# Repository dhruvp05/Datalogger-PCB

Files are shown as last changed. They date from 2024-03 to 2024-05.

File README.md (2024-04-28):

# Datalogger PCB

### Root

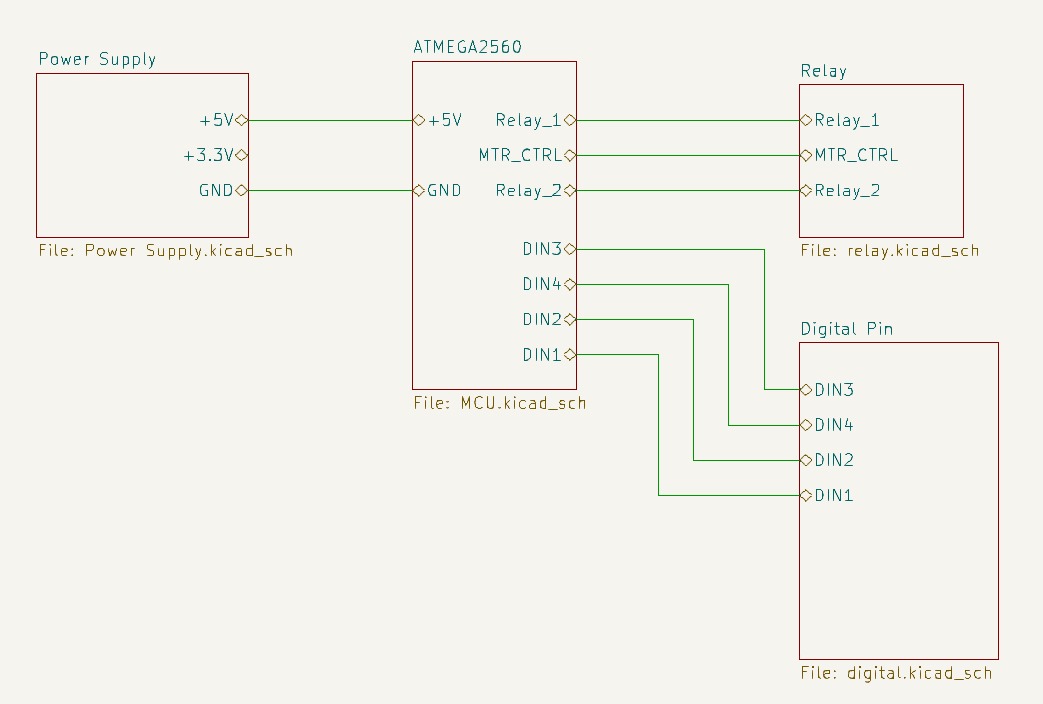
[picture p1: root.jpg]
Root


### Power Supply

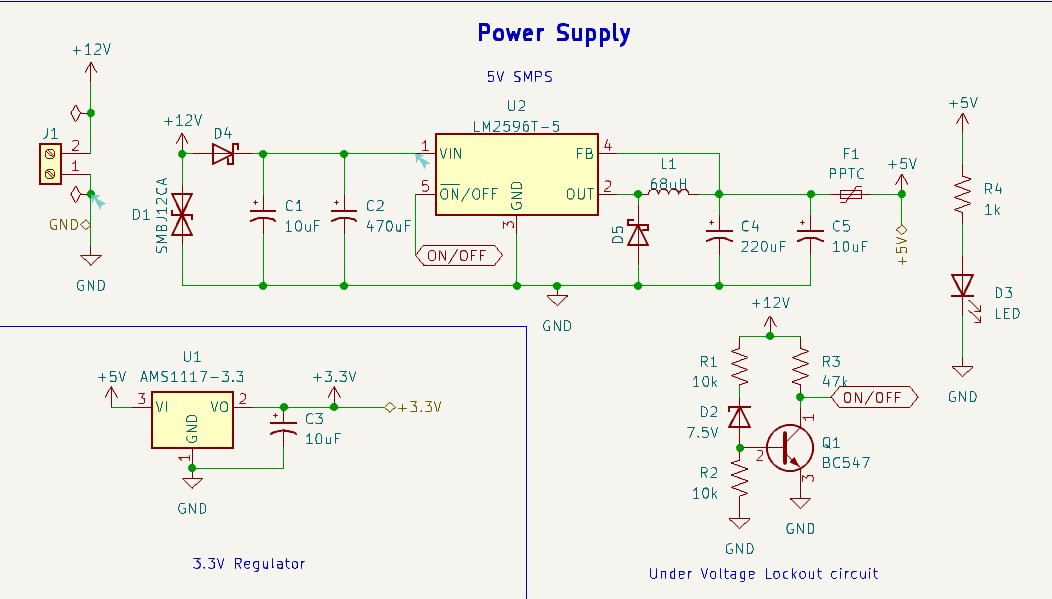
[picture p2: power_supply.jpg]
Power Supply


### Microcontroller

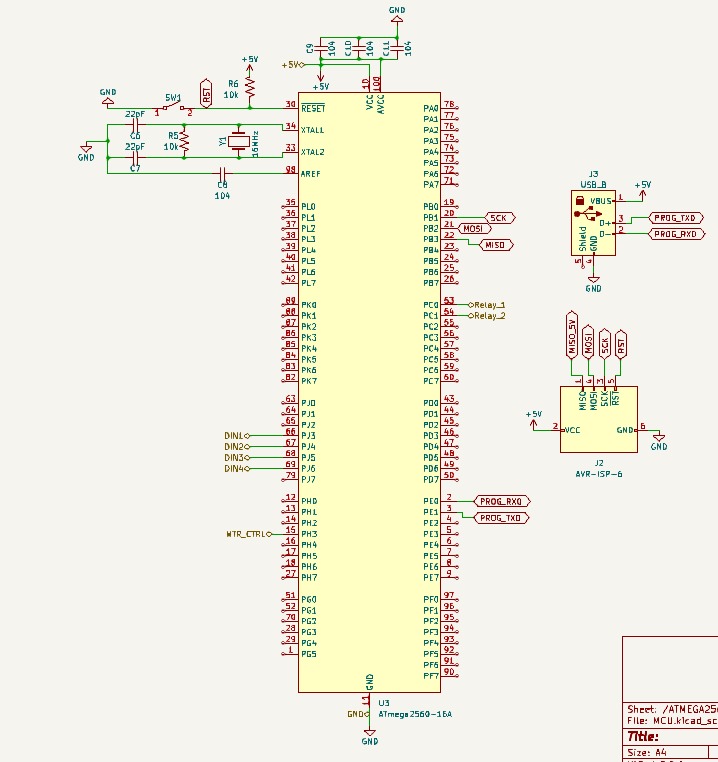
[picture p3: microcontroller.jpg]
Microcontroller


### Relay Motor

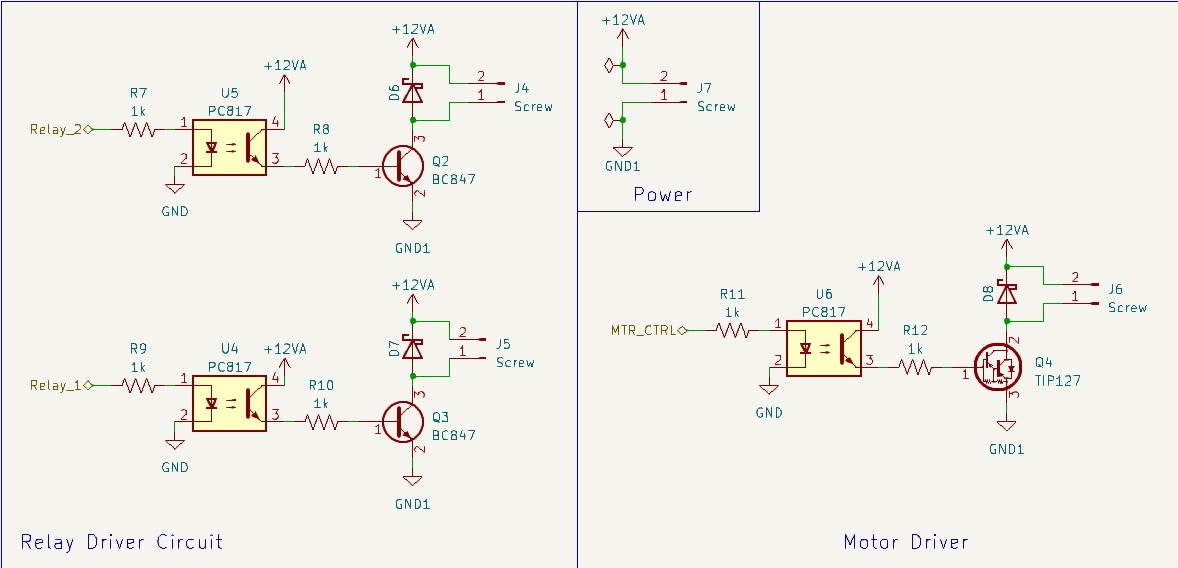
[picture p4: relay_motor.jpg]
Relay Motor


### Digital I/O

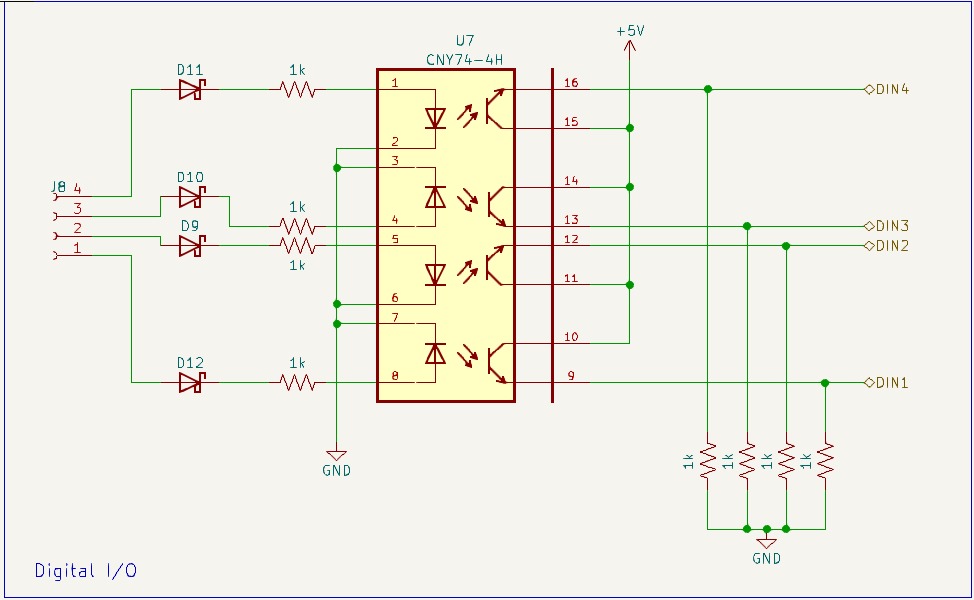
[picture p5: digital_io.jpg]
Digital I/O


### Layout

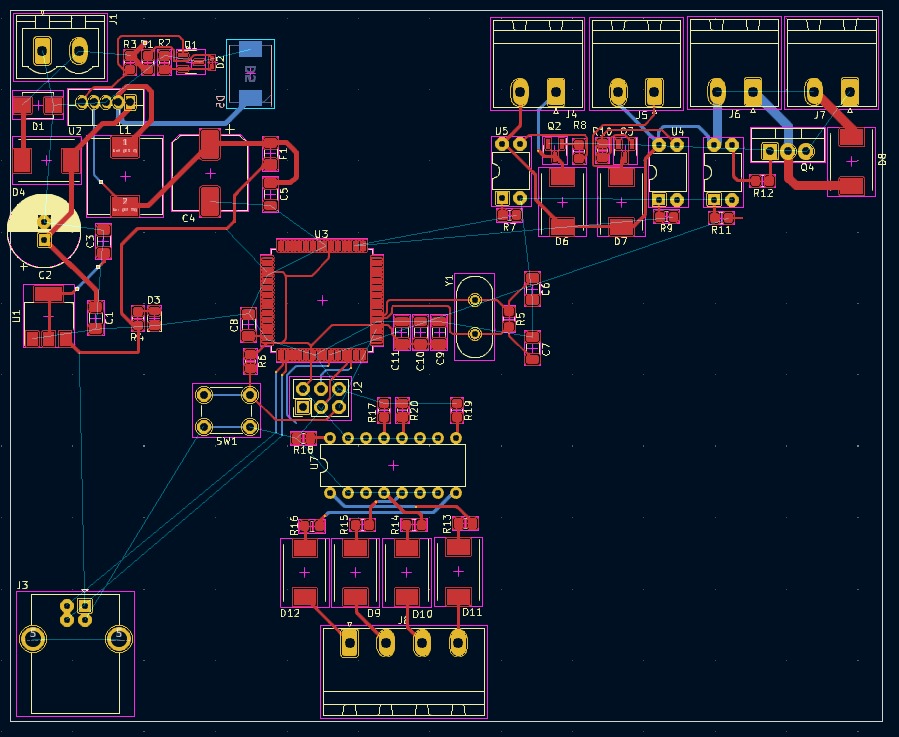
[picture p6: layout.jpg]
Layout


### 3D View

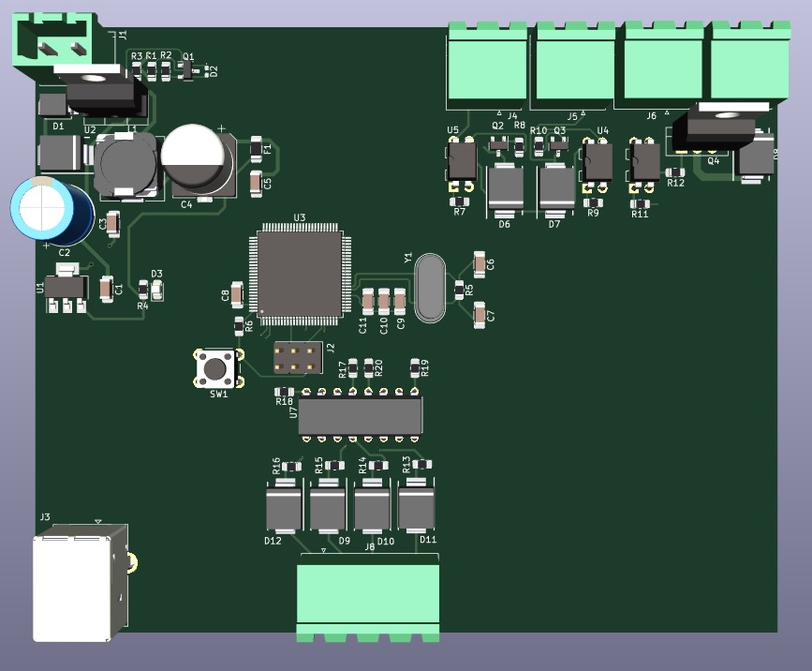
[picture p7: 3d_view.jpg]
3D View


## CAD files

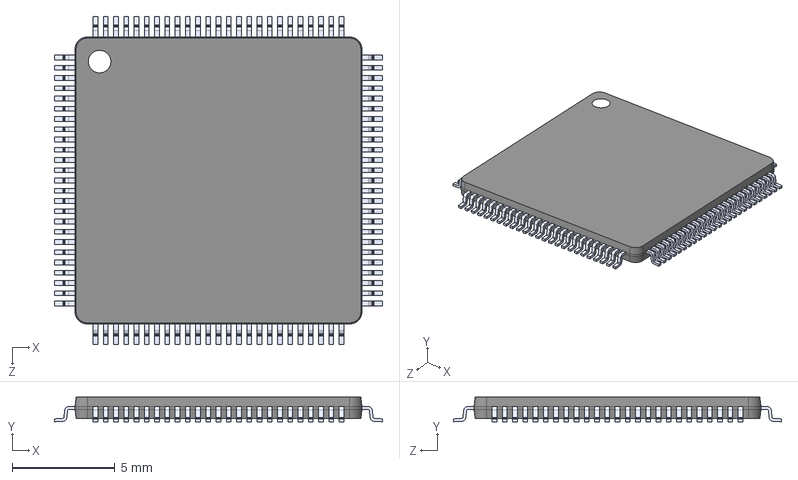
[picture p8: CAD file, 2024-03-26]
ATMEGA2560-16AU.step
16.0 x 1.20 x 16.0 mm

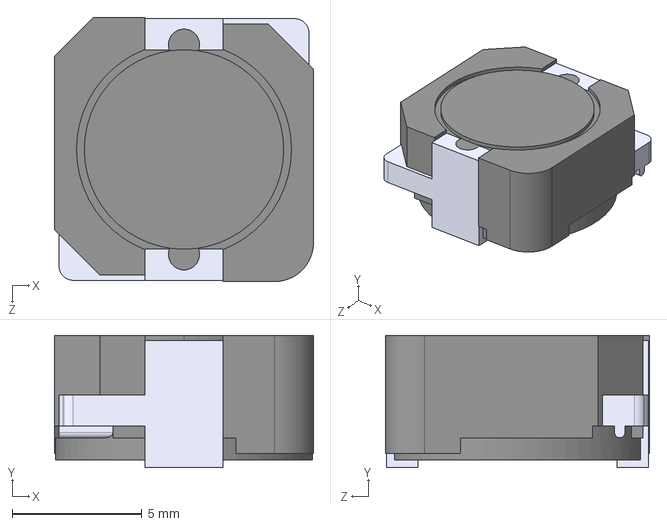
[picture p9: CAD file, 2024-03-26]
CDRH105RNP-151NC--3DModel-STEP-56544.STEP
10.0 x 5.10 x 10.2 mm

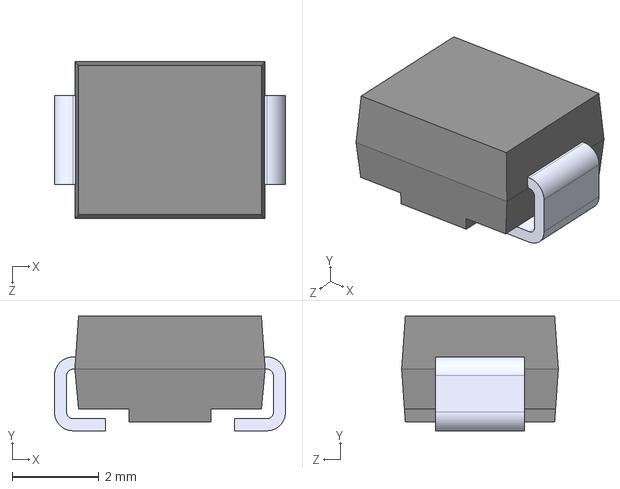
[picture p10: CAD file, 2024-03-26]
SMBJ12CA.STEP
5.34 x 2.65 x 3.62 mm

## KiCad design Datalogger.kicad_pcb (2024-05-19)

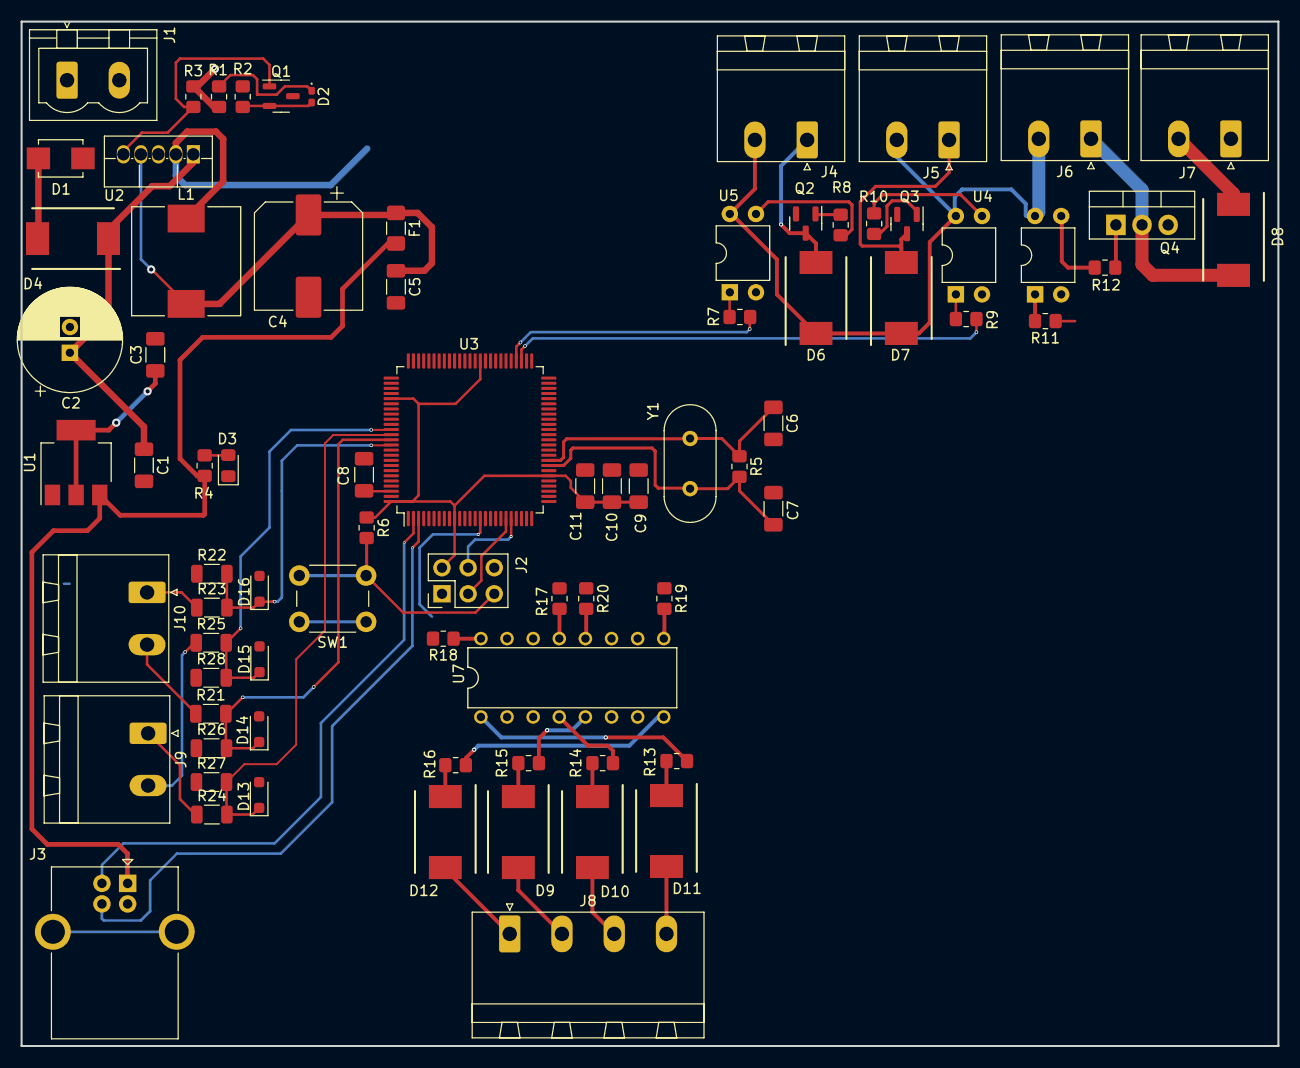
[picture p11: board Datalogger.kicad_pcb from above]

Board: 2 copper layers, 122.2 x 99.6 mm, 80 parts (1 on the bottom side), 60 nets.

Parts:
C1, C3, C5: 10uF; C_1206_3216Metric_Pad1.33x1.80mm_HandSolder
C2: 470uF; CP_Radial_D10.0mm_P2.50mm
C4: 220uF; CP_Elec_10x10
C6, C7: 22pF; C_1206_3216Metric_Pad1.33x1.80mm_HandSolder
C8, C9, C10, C11: 104; C_1206_3216Metric_Pad1.33x1.80mm_HandSolder
D1: SMBJ12CA; DIOM4336X265N
D2: 7.5V; D_0402_1005Metric_Pad0.77x0.64mm_HandSolder
D3: LED; LED_0805_2012Metric_Pad1.15x1.40mm_HandSolder
D4, D5, D6, D7, D8, D9, D10, D11, D12: DIOM8059X256N
D13, D14, D15, D16: 5V; D_SOD-323_HandSoldering
F1: PPTC; Fuse_1206_3216Metric_Pad1.42x1.75mm_HandSolder
J1: From Mains; PhoenixContact_MSTBVA_2,5_2-G-5,08_1x02_P5.08mm_Vertical
J2: AVR-ISP-6; PinHeader_2x03_P2.54mm_Vertical
J3: USB_B; USB_B_OST_USB-B1HSxx_Horizontal
J4, J5, J6, J7, J9, J10: Screw; PhoenixContact_MSTBA_2,5_2-G-5,08_1x02_P5.08mm_Horizontal
J8: Conn_01x04_Socket; PhoenixContact_MSTBA_2,5_4-G-5,08_1x04_P5.08mm_Horizontal
L1: 68uH; L_10.4x10.4_H4.8
Q1: BC547; SOT-23-3
Q2, Q3: BC847; SOT-23
Q4: TIP127; TO-220-3_Vertical
R1, R2, R5, R6: 10k; R_0805_2012Metric_Pad1.20x1.40mm_HandSolder
R3: 47k; R_0805_2012Metric_Pad1.20x1.40mm_HandSolder
R4: 100ohm; R_0805_2012Metric_Pad1.20x1.40mm_HandSolder
R7, R8, R9, R10, R11, R12, R13, R14, R15, R16, R17, R18, R19, R20: 1k; R_0805_2012Metric_Pad1.20x1.40mm_HandSolder
R21, R22, R23, R24, R25, R26, R27, R28: 100k; R_1206_3216Metric
SW1: SW_PUSH_6mm
U1: AMS1117-3.3; SOT-223-3_TabPin2
U2: LM2596T-5; TO-220F-5_Vertical
U3: ATmega2560-16A; TQFP-100_14x14mm_P0.5mm
U4, U5, U6: PC817; DIP-4_W7.62mm
U7: CNY74-4H; DIL16
Y1: 16MHz; Crystal_HC49-4H_Vertical

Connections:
+3.3V: C3.1, U1.2 (VO)
+5V: C9.2, C10.2, C11.2, F1.2, J2.2 (VCC), J3.1 (VBUS), R4.1, R6.1, U1.3 (VI), U3.10 (VCC), U3.31 (VCC), U3.61 (VCC), U3.80 (VCC), U3.100 (AVCC), U7.10, U7.11, U7.14, U7.15
+12V: D1.1 (A1), D4.2 (A), J1.2, R1.1, R3.1
+12VA: D6.1 (K), D7.1 (K), D8.1 (K), J4.2, J5.2, J6.2, J7.2, U4.4, U5.4, U6.4
/ATMEGA2560/DIN1: R19.2, U3.66 (PJ3), U7.9
/ATMEGA2560/DIN2: R20.2, U3.67 (PJ4), U7.12
/ATMEGA2560/DIN3: R17.2, U3.68 (PJ5), U7.13
/ATMEGA2560/DIN4: R18.2, U3.69 (PJ6), U7.16
/ATMEGA2560/MTR_CTRL: R11.1, U3.15 (PH3)
/ATMEGA2560/Relay_1: R9.1, U3.53 (PC0)
/ATMEGA2560/Relay_2: R7.1, U3.54 (PC1)
AIN0: D16.1 (K), R22.2, R23.2, U3.89 (PK0)
AIN1: D14.1 (K), R21.2, R26.2, U3.88 (PK1)
AIN2: D13.1 (K), R24.2, R27.2, U3.87 (PK2)
AIN3: D15.1 (K), R25.2, R28.2, U3.86 (PK3)
GND: C1.2, C2.2, C3.2, C4.2, C5.2, C6.2, C7.2, C8.2, C9.1, C10.1, C11.1, D1.2 (A2), D3.1 (K), D5.2 (A), D13.2 (A), D14.2 (A), D15.2 (A), D16.2 (A), J1.1, J2.6 (GND), J3.4 (GND), Q1.3 (E), R2.2, R17.1, R18.1, R19.1, R20.1, R22.1, R26.1, R27.1, R28.1, SW1.1 (A), U1.1 (GND), U2.3 (GND), U3.11 (GND), U3.32 (GND), U3.62 (GND), U3.81 (GND), U3.99 (GND), U4.2, U5.2, U6.2, U7.2, U7.3, U7.6, U7.7
GND1: J7.1, Q2.2 (E), Q3.2 (E), Q4.3 (E)
MOSI: J2.4 (MOSI), U3.21 (PB2)
unnamed: D2.2 (A), Q1.2 (B), R2.1
unnamed: D2.1 (K), R1.2
unnamed: D3.2 (A), R4.2
unnamed: C1.1, C2.1, D4.1 (K), U2.1 (VIN)
unnamed: D5.1 (K), L1.1, U2.2 (OUT)
unnamed: D6.2 (A), J4.1, Q2.3 (C)
unnamed: D7.2 (A), J5.1, Q3.3 (C)
unnamed: D8.2 (A), J6.1, Q4.2 (C)
unnamed: D9.2 (A), J8.2
unnamed: D9.1 (K), R15.1
unnamed: D10.2 (A), J8.3
unnamed: D10.1 (K), R14.1
unnamed: D11.2 (A), J8.4
unnamed: D11.1 (K), R13.1
unnamed: D12.2 (A), J8.1
unnamed: D12.1 (K), R16.1
unnamed: J9.1, R24.1
unnamed: J9.2, R25.1
unnamed: J10.1, R23.1
unnamed: J10.2, R21.1
unnamed: Q2.1 (B), R8.2
unnamed: Q3.1 (B), R10.2
unnamed: Q4.1 (B), R12.2
unnamed: R7.2, U5.1
unnamed: R8.1, U5.3
unnamed: R9.2, U4.1
unnamed: R10.1, U4.3
unnamed: R11.2, U6.1
unnamed: R12.1, U6.3
unnamed: R13.2, U7.1
unnamed: R14.2, U7.4
unnamed: R15.2, U7.5
unnamed: R16.2, U7.8
unnamed: C4.1, C5.1, F1.1, L1.2, U2.4 (FB)
unnamed: C8.1, U3.98 (AREF)
unnamed: C6.1, R5.1, U3.34 (XTAL1), Y1.2
unnamed: C7.1, R5.2, U3.33 (XTAL2), Y1.1
ON/OFF: Q1.1 (C), R3.2, U2.5 (~ON/OFF)
PROG_RX0: J3.2 (D-), U3.2 (PE0)
PROG_TX0: J3.3 (D+), U3.3 (PE1)
RST: J2.5 (~RST), R6.2, SW1.2 (B), U3.30 (~RESET)
SCK: J2.3 (SCK), U3.20 (PB1)

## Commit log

2024-03-26 Initial commit with power supply and microcontroller layout
    [ATMEGA2560-16AU.step, CDRH105RNP-151NC--3DModel-STEP-56544.STEP, Datalogger.kicad_pcb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]
2024-03-28 "Resolved the issue of SS34 diode footprint. Problem was the pin on the downloaded footprint were not numbered
    [Datalogger.kicad_pcb, Datalogger.kicad_sch, MCU.kicad_sch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]
2024-03-29 Added DC motor driver
    [Datalogger.kicad_pcb, Datalogger.kicad_sch, MCU.kicad_sch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]
2024-04-01 Designed circuit for reading digital input. CHY74 (4 channel optocoupler) used
    [Datalogger.kicad_pcb, Datalogger.kicad_sch, MCU.kicad_sch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]
2024-04-28 Analog input schematic
    [Datalogger.kicad_sch, MCU.kicad_sch, Power Supply.kicad_sch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]
2024-05-19 Schematic of 4-20mA sensor
    [4-20mA_sensor.kicad_sch, Datalogger.kicad_pcb, Datalogger.kicad_sch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]
